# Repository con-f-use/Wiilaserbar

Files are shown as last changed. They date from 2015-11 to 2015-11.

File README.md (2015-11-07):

Wiilaserbar
=================

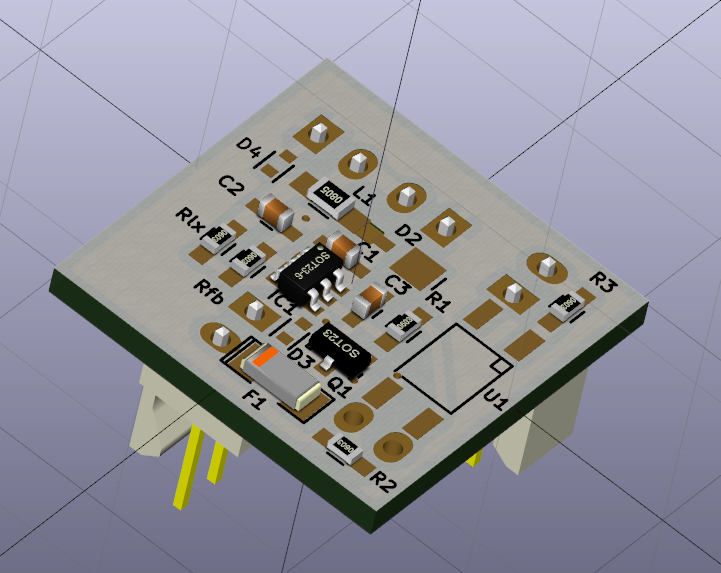
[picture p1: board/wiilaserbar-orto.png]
board


A driver board, case and holder for infrared lasers meant to replace the sensor bar of a Nintendo Wii. 

Be VERY CAREFUL in selecting the output power. Infrared lasers cannot be seen by the naked eye no matter the 
power. They can permanently damage your eyes even at less then 1mW!!! You might blind yourself in an instant!

This is a replacement for the Wii sensor bar. The populatd board powers two infrared laser diode modules. 
These in turn project infrared dots on a surface that the Wiimotes can pick up on just as they were standard
infrared diodes of the "sensor" bar. You can buy infrared laser diode modules on eBay or Aliexpress cheaply.
I used cheap 890nm modules from China said to emit 30mW (the output power with mine was exaggerated -
actually measured power at a university lab was ~2mW).

The driver board was done in KiCAD while the case was 3D modelled in FreeCAD and printed on a LulzBot Mini.

ToDo
==========

 - Case could be smaller and have snapins for the board

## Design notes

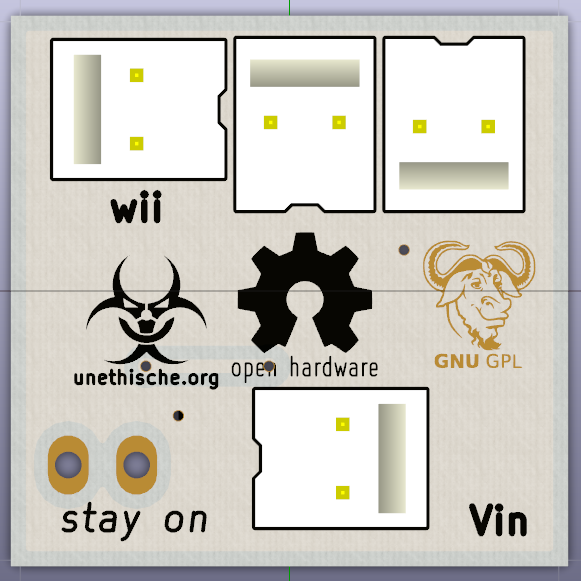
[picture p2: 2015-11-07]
board/wiilaserbar-top.png

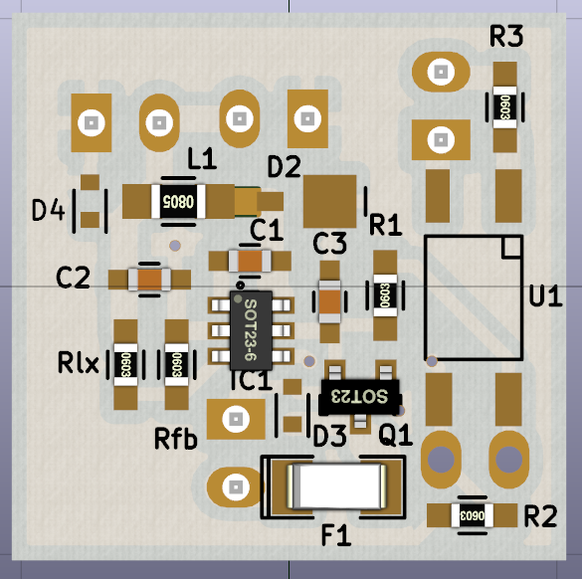
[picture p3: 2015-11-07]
board/wiilaserbar-bottom.png

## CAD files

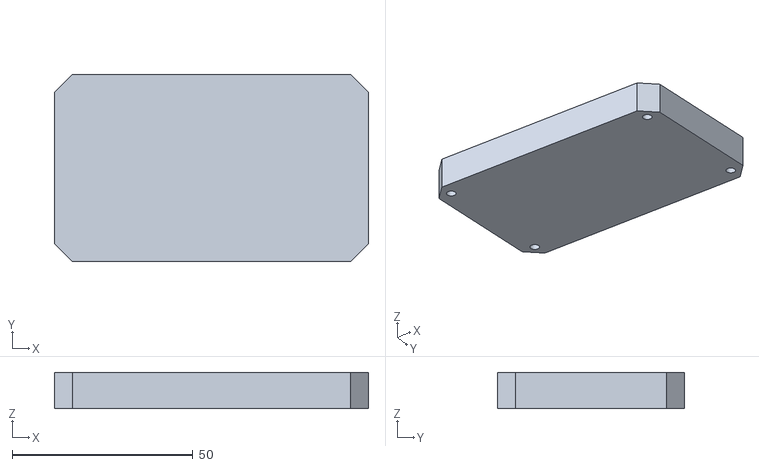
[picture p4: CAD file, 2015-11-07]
case/wiilaserbar_lid_raw.stl
86.8 x 51.8 x 10.0

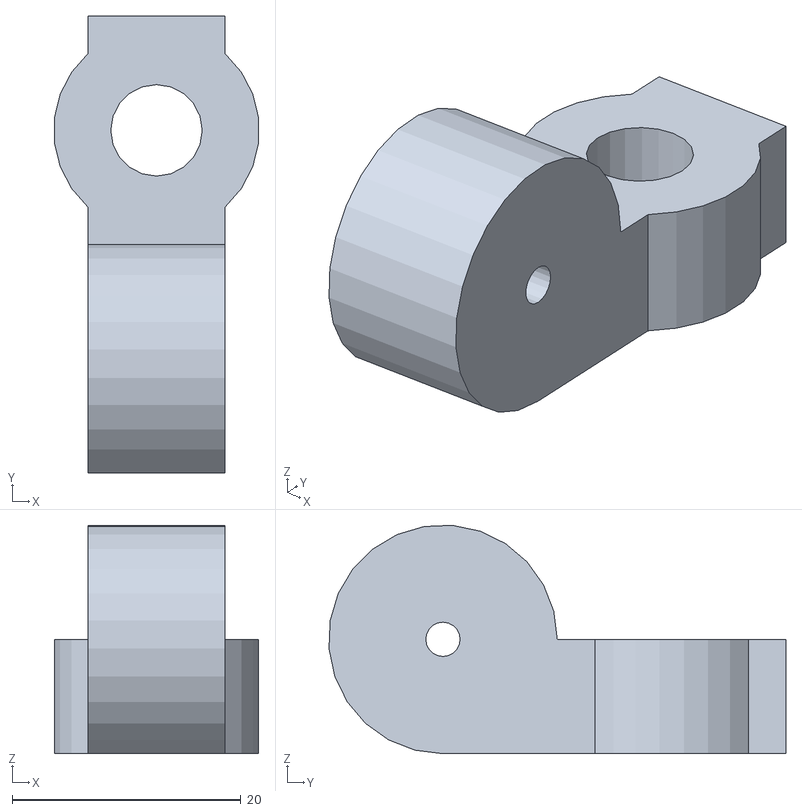
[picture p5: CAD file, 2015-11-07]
case/wiilaserbar_arm_base.stl
17.9 x 40.0 x 20.0

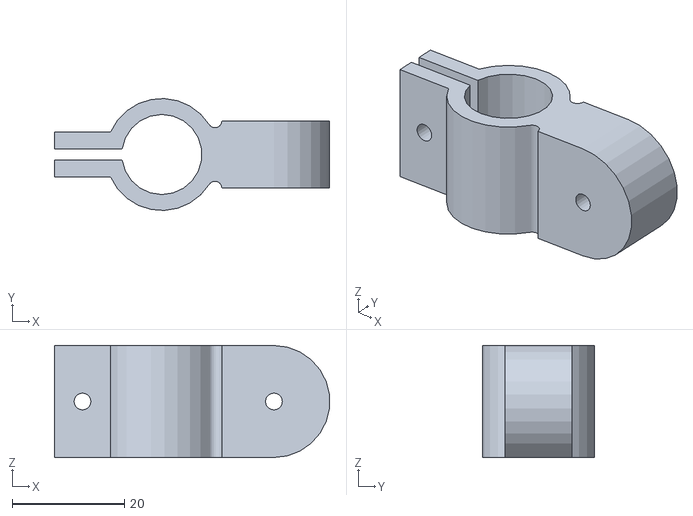
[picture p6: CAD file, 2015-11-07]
case/wiilaserbar_arm_clamp.stl
49.1 x 20.0 x 20.0

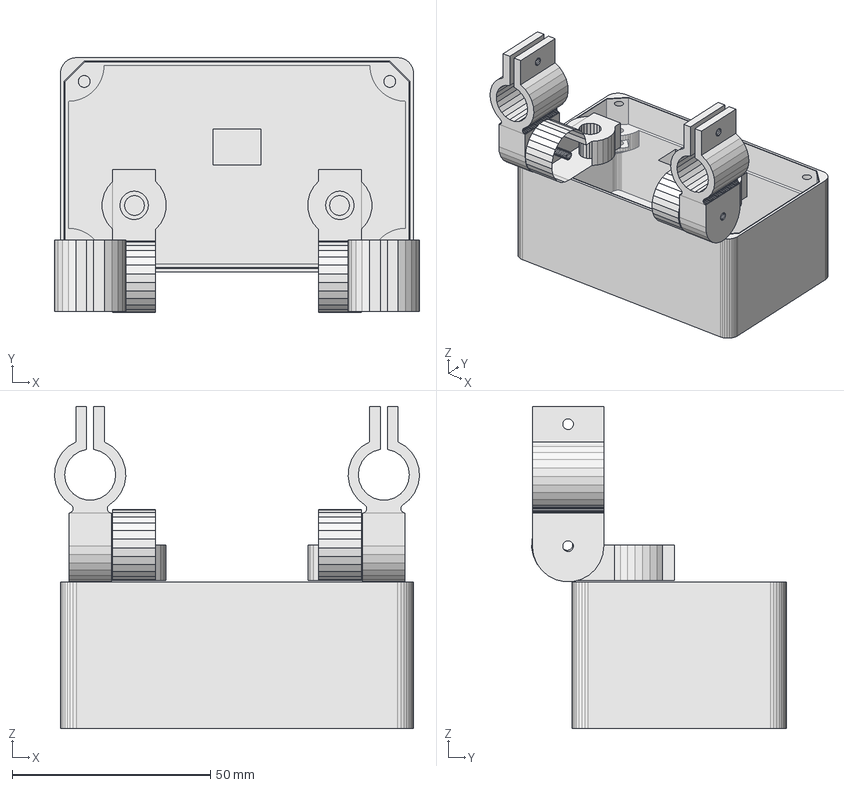
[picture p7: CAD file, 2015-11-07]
case/wiilaserbar_enclosure.fcstd
92.0 x 64.2 x 81.2 mm
cover
enclosure
joint_left
arm_left
joint_right
arm_right

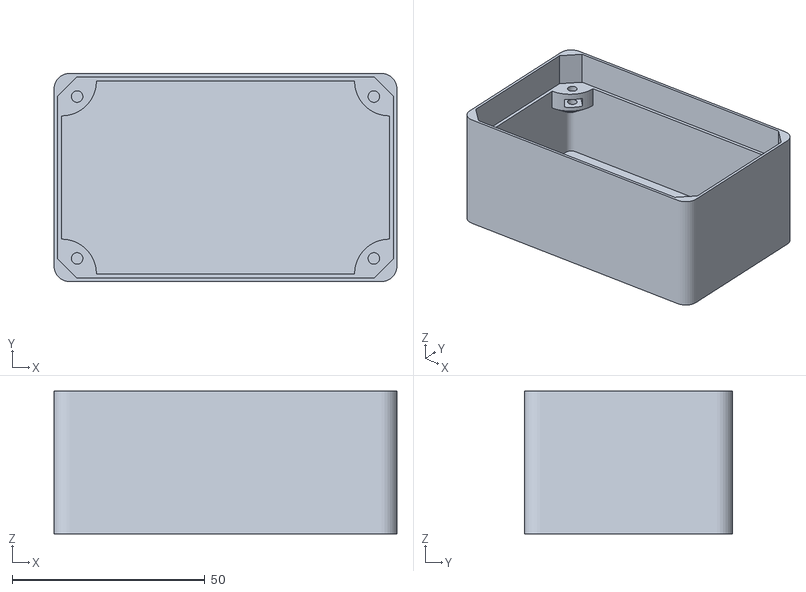
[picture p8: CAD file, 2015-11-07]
case/wiilaserbar_box_raw.stl
89.0 x 54.0 x 37.0

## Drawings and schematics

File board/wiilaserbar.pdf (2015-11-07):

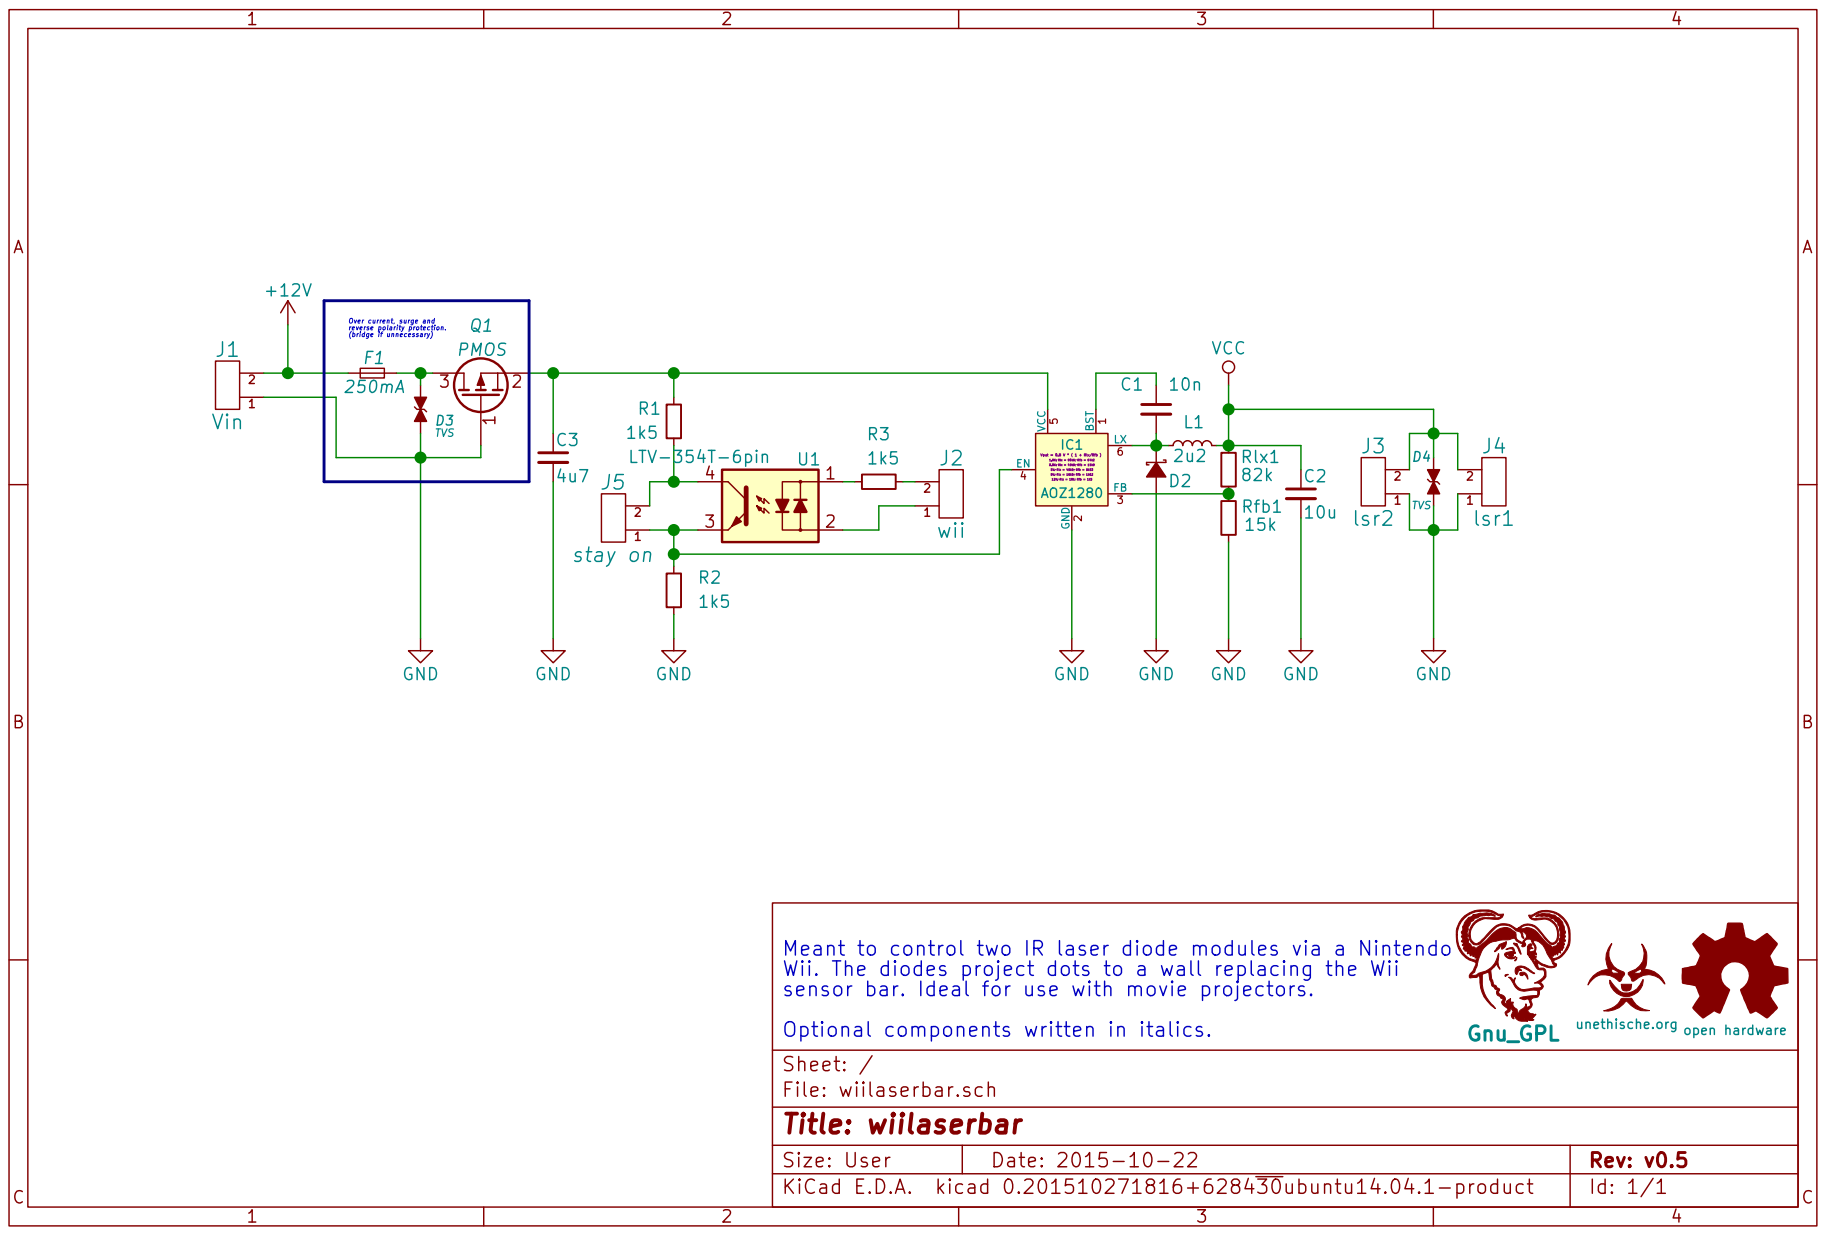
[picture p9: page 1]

Id: 1/1 Title: wiilaserbar File: wiilaserbar.sch Sheet: / R3

Vout = 0.8 V * ( 1 + Rlx/Rfb ) 1.8V: Rlx = 80k6; Rfb = 64k2

unethische.org Meant to control two IR laser diode modules via a Nintendo Wii. The diodes project dots to a wall replacing the Wii
sensor bar. Ideal for use with movie projectors.

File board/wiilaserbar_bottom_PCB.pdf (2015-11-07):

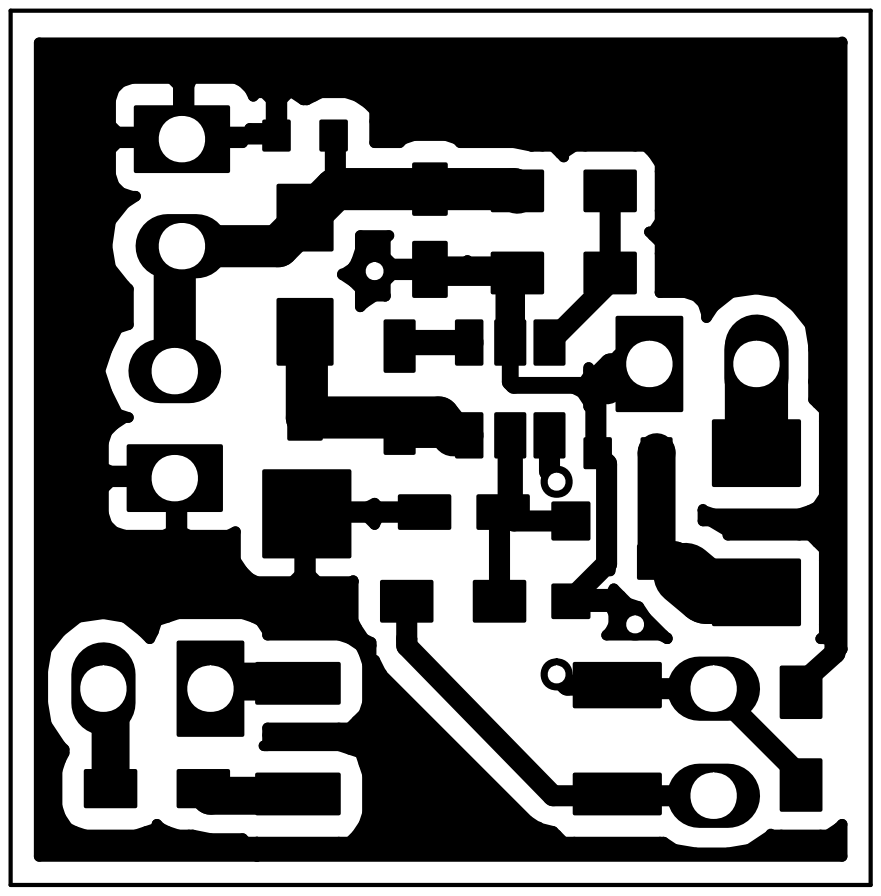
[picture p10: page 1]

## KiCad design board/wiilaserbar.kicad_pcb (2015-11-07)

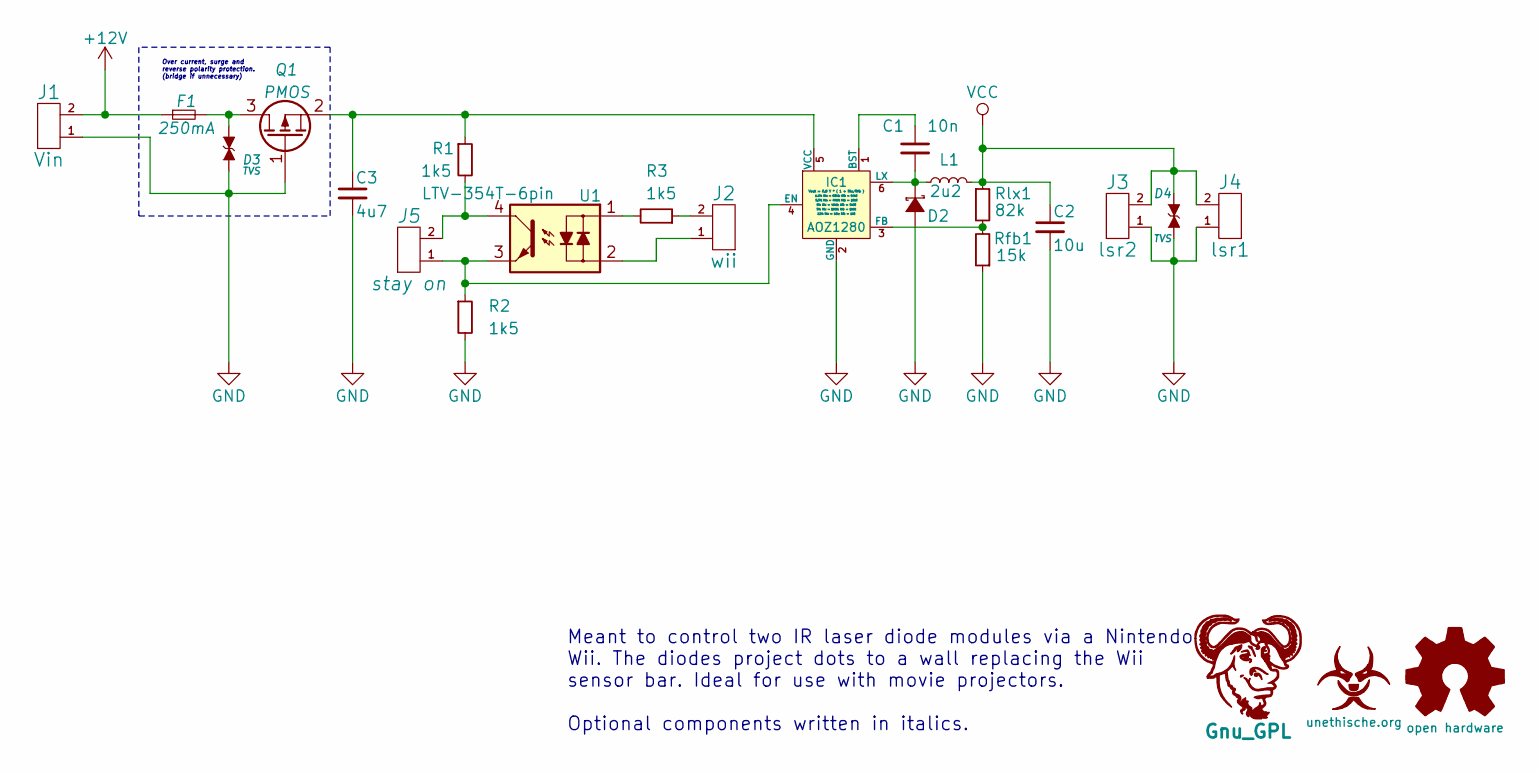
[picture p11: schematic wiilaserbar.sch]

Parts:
C1: 10n; C_0603_HandSoldering
C2: 10u; C_0603_HandSoldering
C3: 4u7; C_0603_HandSoldering
D2: D_Schottky_Small; DIODE_POWERMITE
D3, D4: TVS; SOD-523
F1: 250mA; SMD-1206_Pol
IC1: AOZ1280; SOT-23-6
J1: Vin; kk100_22-23-2021
J2: wii; kk100_22-23-2021
J3: lsr2; kk100_22-23-2021
J4: lsr1; kk100_22-23-2021
J5: stay on; PINHEAD1-2
L1: 2u2; R_0805_HandSoldering
LO1: Gnu_GPL; gnu_gpl
LOGO1: open hardware; Logo_silk_OSHW_6x6mm
O1: unethische.org; unethi_silk
Q1: PMOS; SOT-23
R1, R2, R3: 1k5; R_0603_HandSoldering
Rfb1: 15k; R_0603_HandSoldering
Rlx1: 82k; R_0603_HandSoldering
U1: LTV-354T-6pin; Optocoupler_SMD_HandSoldering_KPC357_LTV35x_PC357_SingleCha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

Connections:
+12V: F1.1, J1.2
GND: C2.2, C3.2, D2.2 (A), D3.2 (K), D4.2 (K), IC1.2 (GND), J1.1, J3.1, J4.1, Q1.1 (G), R2.2, Rfb1.1; also elsewhere on the board
unnamed: C1.1, IC1.1 (BST)
unnamed: C1.2, D2.1 (K), IC1.6 (LX), L1.1
unnamed: C3.1, IC1.5 (VCC), Q1.2 (S), R1.1
unnamed: D3.1 (A), F1.2, Q1.3 (D)
unnamed 6: IC1.3 (FB), Rfb1.2, Rlx1.2; also elsewhere on the board
unnamed: IC1.4 (EN), J5.1, R2.1, U1.3
unnamed: J2.1, U1.2
unnamed: J2.2, R3.1
unnamed: J5.2, R1.2, U1.4
unnamed: R3.2, U1.1
VCC: C2.1, D4.1 (A), J3.2, J4.2, L1.2, Rlx1.1; also elsewhere on the board

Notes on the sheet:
Meant to control two IR laser diode modules via a Nintendo Wii. The diodes project dots to a wall replacing the Wii sensor bar. Ideal for use with movie projectors. Optional components written in italics.
Over current, surge and reverse polarity protection. (bridge if unnecessary)

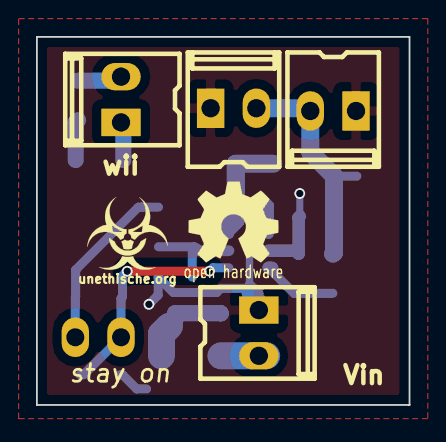
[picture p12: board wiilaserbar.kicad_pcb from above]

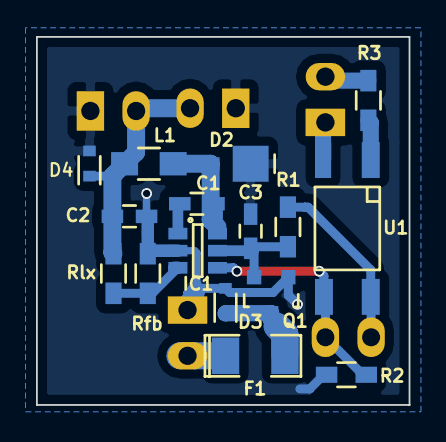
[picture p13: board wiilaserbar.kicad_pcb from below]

Board: 2 copper layers, 20.7 x 20.4 mm, 24 parts (16 on the bottom side), 13 nets.

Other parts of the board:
Rfb: 15k; R_0603_HandSoldering
Rlx: 82k; R_0603_HandSoldering

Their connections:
GND: Rfb.1; also elsewhere on the board
unnamed 6: Rfb.2, Rlx.2; also elsewhere on the board
VCC: Rlx.1; also elsewhere on the board
